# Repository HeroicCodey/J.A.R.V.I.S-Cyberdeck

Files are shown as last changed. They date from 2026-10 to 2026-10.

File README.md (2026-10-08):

# J.A.R.V.I.S-Cyberdeck
An Esp32 Based Cyberdeck using 1.8 inch TFT and four buttons (And of course 30 pin ESP-32).

The "Atlantis V2" project is a Tier 3 custom-built, portable ESP32-based cyberdeck and smart device system, featuring a firmware environment dubbed "J.A.R.V.I.S. Core V.01" or "Retro-OS". Designed by pilot/operator Sloke Bhattacharyya, the project functions as a multi-module tactical terminal integrated with cellular and network diagnostics, arcade games, and productivity tools.

**Hardware Specifications**

* **Microcontroller:** The system is powered by an ESP32 Development Board, specifically a NodeMCU-32S or ESP32-WROOM-32.
* **Display:** It utilizes a 1.8-inch SPI TFT LCD Display driven by an ST7735 controller with a 128x160 pixel resolution.
* **Input Interface:** Navigation is handled by a physical matrix of four tactile push buttons mapped to Nav, Prev, Select, and Back actions.
* **Connectivity Hardware:** Cellular capabilities are provided by an A7670C 4G LTE Module using a UART2 interface.
* **Power Architecture:** The device runs on a single 18650 Lithium-ion battery cell paired with a TP4056/BMS protection board.

**User Interface and Display Design**

* **Aesthetic Paradigm:** The interface is modeled after a simplistic, monochromatic Linux terminal.
* **Menu System:** Navigation relies on a horizontal camera-roll carousel featuring an animated viewfinder box to highlight active selections.
* **Display Orientation:** The software enforces a 180-degree display rotation (`tft.setRotation(2)`) to accommodate the physical mounting orientation of the screen.
* **Theme Engine:** The UI supports custom color palettes, including "OBSIDIAN" (black with magenta highlights), "MATRIX" (black with emerald green), and "LAPIS" (obsidian base with cyan-dominant telemetry).

**Software Modules and Applications**

* **Boot Sequence:** The system features a multi-stage fake Linux boot sequence, complete with rootfs mounting, SPI initialization, a CRT beam raster expansion effect, and an encrypted "HELLO SLOKE" operator greeting.
* **E.D.I.T.H. Tactical Diagnostics:** A dedicated network module capable of WiFi access point scanning, subnet discovery (pinging local IPs to map active hosts), and RSSI signal mapping.
* **F.R.I.D.A.Y. Web Portal:** The ESP32 hosts a local Access Point and web server that allows users to remotely configure WiFi credentials, manage a tactical "To-Do" directive list, and upload text files (TXT, JSON, CSV) directly to the device's LittleFS flash storage.
* **Productivity Tools:** The firmware includes a built-in text reader for displaying uploaded files, a virtual on-screen keyboard for standalone text entry, and a clock application featuring NTP network time synchronization, a countdown timer, and a stopwatch.
* **Arcade Games Suite:** The device includes a fully persistent, high-score tracking game engine containing six titles:
* *Space Impact:* A vertical space shooter featuring progressive difficulty, drone and interceptor enemy classes, and a dynamic spawn rate.
* *Cyber Snake:* A classic grid-based snake game.
* *Cyber Bird:* A physics-based Flappy Bird clone.
* *Firewall Breach:* A Breakout-style block-busting game.
* *Neon Overdrive:* A three-lane vertical racing/dodging game.
* *Lunar Descent:* A physics-based lunar lander simulation requiring precise thrust and angle management.

[BOM.csv](https://github.com/user-attachments/files/33223327/BOM.csv)



[Atlantis V2.pdf](https://github.com/user-attachments/files/33223259/Atlantis.V2.pdf)
Item No.,Part Name,Quantity
1,ESP32 30-pin,1
2,4-pin Tactile Button,4
3,1.8 in Touchless TFT,1

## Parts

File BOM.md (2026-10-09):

# ESP32 DEV BOARD – bill of materials

<!-- Generated by Half Life from project cmuuvkhvl0azl01sm9hbykhbl. Edits here are overwritten on the next sync. -->
<!-- Generated: 2026-10-09T17:57:20.637Z -->

> [!NOTE]
> This parts list is mirrored from [Half Life](https://halflife.hackclub.com). Editing it here will not change the platform's copy, and the next sync overwrites this file.

| Week | Tier | Parts funding |
| --- | --- | --- |
| Week 1 | Tier 2 | $65.00 |

| Part | What it's for | Qty | Unit | Total | Vendor |
| --- | --- | --- | --- | --- | --- |
| [ESP32 30-pin](https://www.digikey.com/en/products/detail/espressif-systems/ESP32-DEVKITC-32E/12091810) | Main Microcontroller | 1 | $10.00 | $10.00 | [Digikey](https://www.digikey.com/en/products/detail/espressif-systems/ESP32-DEVKITC-32E/12091810) |
| [4-pin Tactile Button](https://www.digikey.com/en/products/detail/omron-electronics-inc-emc-div/B3F-4050/36735) | Controls | 4 | $0.60 | $2.40 | [Digikey](https://www.digikey.com/en/products/detail/omron-electronics-inc-emc-div/B3F-4050/36735) |
| [1.8 in Touchless TFT](https://www.digikey.com/en/products/detail/sparkfun-electronics/15143/10064420) | Main Display | 1 | $35.00 | $35.00 | [Digikey](https://www.digikey.com/en/products/detail/sparkfun-electronics/15143/10064420) |
| [18650](https://www.digikey.com/en/products/detail/jauch-quartz/LI18650JLS-HB-3-35AH-PROTECTED/13538411) | Battery | 1 | $15.00 | $15.00 | [Digikey](https://www.digikey.com/en/products/detail/jauch-quartz/LI18650JLS-HB-3-35AH-PROTECTED/13538411) |
| **Parts subtotal** | — | — | — | **$62.40** | — |
| **Tax & shipping** | — | — | — | **$2.50** | — |
| **Total** | — | — | — | **$64.90** | — |

$0.10 left of the tier's funding.

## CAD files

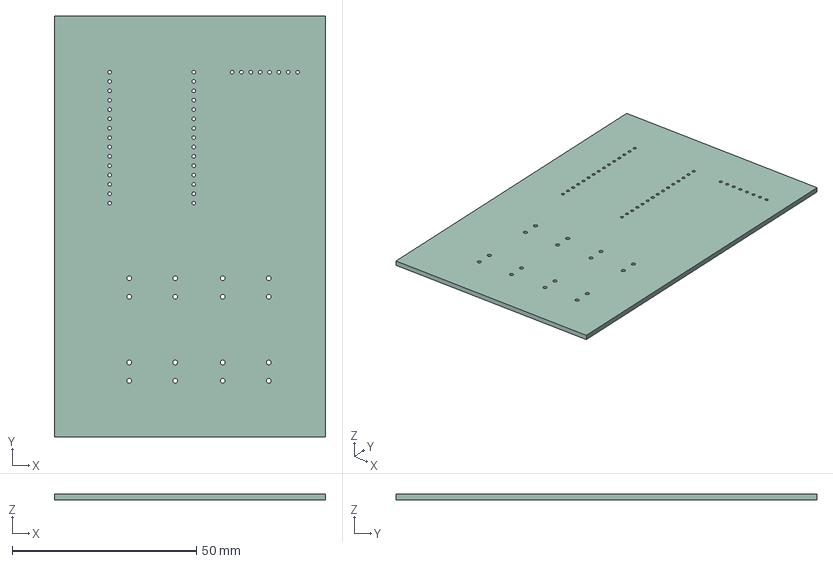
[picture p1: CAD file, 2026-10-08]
JARVIS.step
73.7 x 114.3 x 1.51 mm

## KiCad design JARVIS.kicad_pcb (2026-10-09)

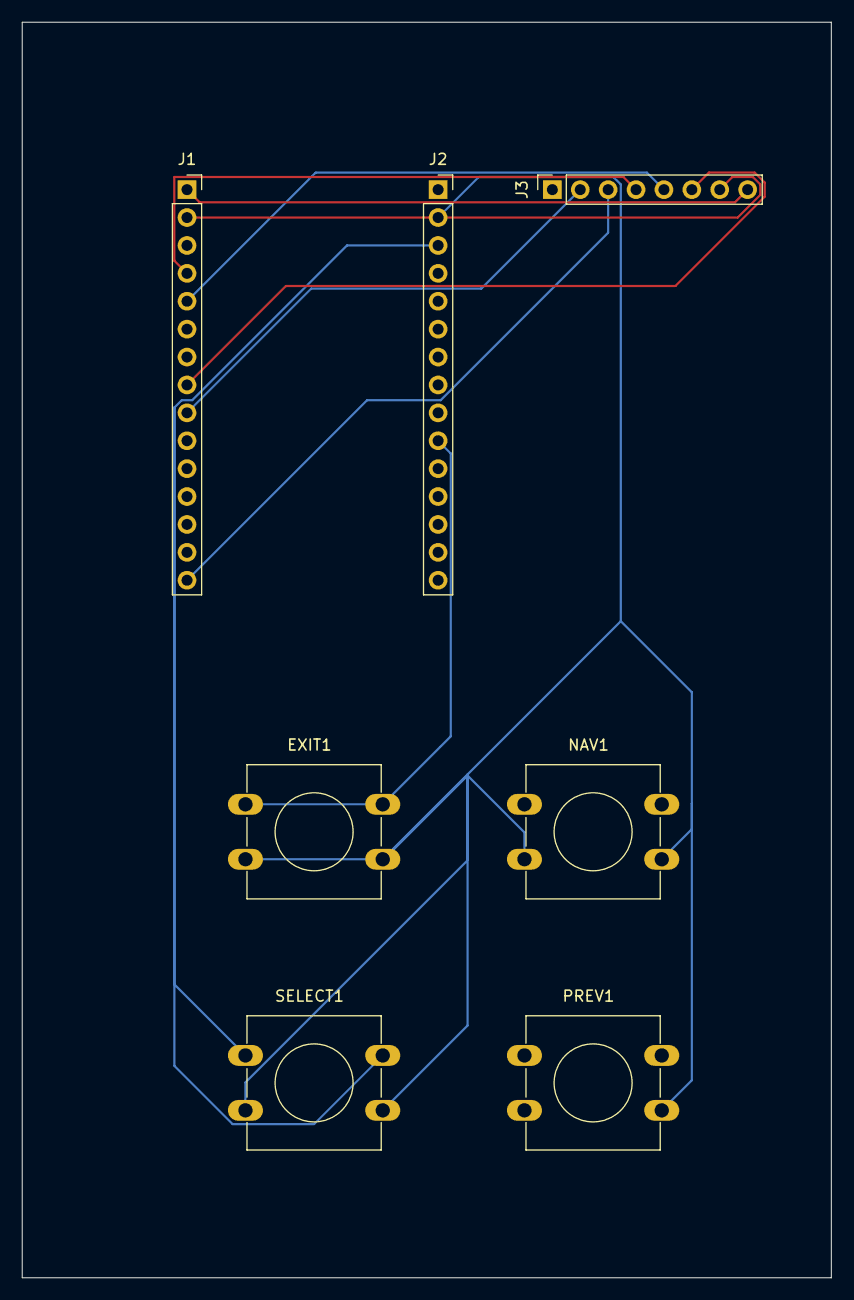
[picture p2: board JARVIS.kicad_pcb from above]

Board: 4 copper layers, 73.7 x 114.3 mm, 7 parts (0 on the bottom side), 11 nets.

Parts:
EXIT1: SW_Push; SW_PUSH-12mm
J1, J2: Conn_01x15; PinSocket_1x15_P2.54mm_Vertical
J3: Conn_01x08; PinSocket_1x08_P2.54mm_Vertical
NAV1: SW_Push; SW_PUSH-12mm
PREV1: SW_Push; SW_PUSH-12mm
SELECT1: SW_Push; SW_PUSH-12mm

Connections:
/3v3: J1.1, J3.1, J3.8
/D2: J1.4, J3.4
/D4: J1.5, J3.5
/D5: J1.8, J3.6
/D13: J2.3, SELECT1.1
/D14: J2.5, NAV1.1
/D18: J1.9, J3.2
/D23: J1.15, J3.3
/D27: J2.6, PREV1.1
/D32: EXIT1.1, J2.10
GND: EXIT1.2, J1.2, J2.2, J3.7, NAV1.2, PREV1.2, SELECT1.2

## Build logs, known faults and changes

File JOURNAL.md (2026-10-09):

# ESP32 DEV BOARD – devlog

<!-- Generated by Half Life from project cmuuvkhvl0azl01sm9hbykhbl. Edits here are overwritten on the next sync. -->
<!-- Generated: 2026-10-09T17:10:21.980Z -->

> [!NOTE]
> This devlog is mirrored from [Half Life](https://halflife.hackclub.com). Editing it here will not change the platform's copy, and the next sync overwrites this file.

> A fully functional diagnostic dev board for early prototyping. V0.01 Is the Basic version Without Sim integration.

| Week | Tier | Hours logged | Entries |
| --- | --- | --- | --- |
| Week 1 | Tier 2 | 16.03h | 3 |

## Contents

1. [2026-10-05 – Worked Out The Basics.](#2026-10-05-worked-out-the-basics)
2. [2026-10-08 – Selected Specific Parts Suitable By Going Through The Specs Sheet Of Each And Every Item. Here Are The Main Ones:](#2026-10-08-selected-specific-parts-suitable-by-going-through)
3. [2026-10-09 – Work session (3 Hours) + Creating A Writeup And Github Page (1 Hour)](#2026-10-09-work-session-3-hours-creating-a-writeup-and-githu)

## Design

### 2026-10-05 – Worked Out The Basics.

**3h**

Worked Out The Basics.
Created A List And BOM For the project. Sourced links to cheapest resources. Mapped out the UI design
to be simplistic monochromatic Linux Terminal type,
Menu: Carousel(Horizontal)
Color themes: Obsidian(Magenta), Emerald(Green),Lapis(Cyan-My fav for now)







### 2026-10-08 – Selected Specific Parts Suitable By Going Through The Specs Sheet Of Each And Every Item. Here Are The Main Ones:

**6h**

Selected Specific Parts Suitable By Going Through The Specs Sheet Of Each And Every Item. Here Are The Main Ones:



The A7670C Module supports wireless communication modes of LTE-TDD/LTE-FDD/GSM/GPRS/EDGE. It supports maximum 10Mbps downlink rate and 5Mbps uplink rate. The A7670 series supports multiple built-in network protocols, supports drivers for main operation systems (USB driver for Windows, Linux and Android etc.) and software function, AT commands are compatible with SIM7500/SIM7600 series modules.

The A7670 series adopts LGA form factor and is compatible with SIM7000/SIM7070 series, and SIM800A/SIM800F(2G modules) which enables smooth migration from 2G/NB/Cat M products to LTE Cat 1 products, and greatly facilitates more compatible product design for the customer needs.

Meanwhile the A7670 series integrates main industrial standard interfaces, with powerful expansibility, including abundant interfaces such as UART, USB, I2C, GPIO, which is suitable for main IOT applications such as telematics, surveillance devices, POS, industrial routers, remote diagnostics etc.

Features :

Small size  LTE Cat 1 module
Supports  LTE-FDD, LTE-TDD, and GSM, frequency bands
Control via AT commands
SIM Card Holder
Power LED and Network Status
Powerful TCP/IP protocol stack for internet data transfer
Supports maximum 10Mbps downlink rate and 5Mbps uplink rate
DC Jack input voltage  :  7-12V
RS232  DB9 Connector interface
SMA  connector for external antenna
1.8V UART header
Abundant software functions  : FOTA, LBS, SSL
The form factor of A7670 series are compatible with the SIM7000/SIM7070 series

Documents:

Datasheet

Package includes :

1 x A7670C 4G/2G Module

ESP32 38-Pin WiFi + Bluetooth NodeMCU Development Board
The ESP32 38-Pin WiFi + Bluetooth NodeMCU Development Board is a versatile microcontroller development board designed for IoT, home automation, robotics, embedded systems, and wireless electronics projects. Built around the ESP-WROOM-32 module, it combines a powerful dual-core processor with built-in WiFi and Bluetooth connectivity, allowing you to develop connected applications without requiring separate wireless modules.

With 38 pins and multiple GPIO, PWM, ADC, DAC, UART, SPI, and I2C interfaces, the board provides flexible connectivity for sensors, displays, motors, relays, and other electronic components. Its compatibility with the Arduino IDE makes it accessible to students and beginners while providing the processing capability required for more advanced IoT and embedded projects.

Whether you are developing a smart home system, wireless sensor network, robotics project, data logger, or connected prototype, this ESP32 development board provides a practical combination of processing power, wireless connectivity, and peripheral support.

The board is also suitable for developers looking for an affordable ESP32 NodeMCU board for IoT and embedded applications, with a large developer community and extensive software support.

Features
ESP-WROOM-32 Module
The ESP-WROOM-32 module combines processing and wireless capabilities in a compact platform, making it suitable for connected IoT and embedded applications.

Dual-Core Processor
The dual-core processor provides the processing capability needed for multitasking applications involving wireless communication, sensors, automation, and data processing.

Built-in WiFi & Bluetooth
Integrated WiFi and Bluetooth allow the board to communicate wirelessly with networks, smartphones, sensors, and other connected devices without requiring additional communication modules.

38-Pin Design
The 38-pin layout provides access to multiple GPIO and peripheral interfaces, giving developers greater flexibility when connecting sensors, displays, motors, and other components.

Arduino IDE Compatibility
Arduino IDE compatibility simplifies programming and prototyping, making the board suitable for beginners as well as experienced developers working on ESP32 projects.

Low-Power Operation
Its power-efficient design makes the ESP32 suitable for battery-powered IoT devices, wireless sensors, monitoring systems, and other embedded applications.

1.8 inch TFT LCD Module
This is the 1.8 inch TFT LCD Module. This TFT LCD display module communicates via 4-wire SPI and has its own pixel-addressable frame buffer; it can be used with any type of microcontroller, even very small ones with limited memory and few available pins.

The 1.8″ TFT LCD display features 128×160 colour pixels. This display is a true TFT, unlike low-cost “Nokia 6110” and similar LCD displays, which are CSTN type and thus have poor colour and slow refresh. The ST7735R TFT driver can display full 18-bit colour (262,144 shades!), making it ideal for vibrant graphical interfaces.

If you're comparing the 1.8 inch TFT LCD price India, this module offers a great balance between performance and affordability for DIY electronics, embedded systems, and IoT projects.

The LCD will always come with the same driver chip, so you won’t have to worry about compatibility issues across units. The TFT display is soldered to the breakout (using a delicate flex-circuit connector), along with an ultra-low-dropout 3.3V regulator and a 3/5V level shifter, allowing seamless use with both 3.3V and 5V systems.

If you want to use this 1.8 inch TFT LCD display Module with Arduino, in your project for that you will need few essential components like

breadboard
jumper wires
Features:
Display Size: 1.8 inch TFT
Resolution: 128 × 160 pixels
Driver IC: ST7735R
Interface: SPI (4-wire)
Operating Voltage: 3.3V / 5V compatible
Built-in voltage regulator and level shifter
Full RGB colour support (18-bit)
Compact and lightweight design











### 2026-10-09 – Work session (3 Hours) + Creating A Writeup And Github Page (1 Hour)

**7.03h**

Work session (3 Hours) + Creating A Writeup And Github Page (1 Hour)

[Timelapse](https://lookout.hackclub.com/api/media/f1b2b3fd-91bf-4616-979b-26d5c6f9fb0f/video.mp4)

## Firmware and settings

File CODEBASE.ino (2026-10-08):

//Code Written In Arduino Language
#include <Adafruit_GFX.h>
#include <Adafruit_ST7735.h>
#include <SPI.h>
#include <WiFi.h>
#include <esp_wifi.h>
#include <WebServer.h>
#include <LittleFS.h>
#include <time.h>
#include <Preferences.h>
#include <esp_system.h>
#include <math.h>

// =============================================================================
// HARDWARE DEFINITIONS & DISPLAY SETUP
// =============================================================================
#define TFT_CS    5
#define TFT_RST   4
#define TFT_DC    2

Adafruit_ST7735 tft = Adafruit_ST7735(TFT_CS, TFT_DC, TFT_RST);
Preferences prefs;
WebServer server(80);

#define ENABLE_PHYSICAL_BUTTONS 1

#define PIN_BTN_NAV    14  // Hardware Button 0 (Red cap)
#define PIN_BTN_PREV   27  // Hardware Button 1 (Blue cap)
#define PIN_BTN_SEL    13  // Hardware Button 2 (White cap)
#define PIN_BTN_BACK   32  // Hardware Button 3 (Amber cap)

// =============================================================================
// WI-FI & NTP CONFIGURATION
// =============================================================================
const char* WIFI_SSID     = "AirFiber+";
const char* WIFI_PASSWORD = "11223344";

const char* AP_SSID        = "FRIDAY-CORE";
const char* AP_PASS        = "cyberdeck32";

const char* NTP_SERVER_1  = "pool.ntp.org";
const char* NTP_SERVER_2  = "time.nist.gov";
const long  NTP_GMT_OFFSET_SEC      = 19800; // IST UTC+5:30
const int   NTP_DAYLIGHT_OFFSET_SEC = 0;

const unsigned long WIFI_BOOT_TIMEOUT_MS = 6000;
const unsigned long NTP_BOOT_TIMEOUT_MS  = 4000;
const size_t MIN_SAFE_HEAP_BYTES = 40960; // 40 KB Safety ceiling

// =============================================================================
// COLOR PALETTES & THEME ENGINE
// =============================================================================
struct ThemePalette {
  const char* name;
  uint16_t bg;
  uint16_t primary;
  uint16_t secondary;
  uint16_t dim;
  uint16_t steel;
  uint16_t highlight;
};

const ThemePalette THEMES[] = {
  {"OBSIDIAN",   0x0082, 0x07FF, 0xFD00, 0x03F5, 0x1A29, 0xAD7F},
  {"MATRIX",     0x0000, 0x07E0, 0x05E0, 0x0320, 0x0200, 0x87F0},
  {"SYNTHWAVE",  0x1012, 0xF81F, 0x07FF, 0x8010, 0x3018, 0xFFE0}
};
const uint8_t TOTAL_THEMES = sizeof(THEMES) / sizeof(THEMES[0]);
uint8_t currentThemeIdx = 0;

#define COLOR_BG          THEMES[currentThemeIdx].bg
#define COLOR_AMBER       THEMES[currentThemeIdx].secondary
#define COLOR_CYAN        THEMES[currentThemeIdx].primary
#define COLOR_CYAN_DIM    THEMES[currentThemeIdx].dim
#define COLOR_STEEL       THEMES[currentThemeIdx].steel
#define COLOR_ICE         THEMES[currentThemeIdx].highlight
#define COLOR_LIME        0x07E0
#define COLOR_BLACK       0x0000
#define COLOR_WHITE       0xFFFF

// Hardware Button Colors
#define HW_COLOR_RED      0xF800
#define HW_COLOR_BLUE     0x001F
#define HW_COLOR_WHITE    0xFFFF
#define HW_COLOR_AMBER    0xFBE0

const uint16_t HW_BTN_COLORS[4] = {
  HW_COLOR_RED,   
  HW_COLOR_BLUE,  
  HW_COLOR_WHITE, 
  HW_COLOR_AMBER  
};

// =============================================================================
// SYSTEM & STATE DEFINITIONS
// =============================================================================
enum BootState {
  BOOT_STATE_VERSION,
  BOOT_STATE_LINUX_LOGS,
  BOOT_STATE_CRT_BEAM,
  BOOT_STATE_RASTER_EXPAND,
  BOOT_STATE_GRID_SCAN,
  BOOT_STATE_DECRYPT_NAME,
  BOOT_STATE_SYS_LOCK,
  BOOT_STATE_IDLE
};

enum AppState {
  STATE_BOOTING, STATE_HOMESCREEN, STATE_ROLL_MENU, STATE_APP_ACTIVE,
  STATE_APP_CLOCK, STATE_APP_GAMES, STATE_APP_SETTINGS, STATE_APP_FRIDAY,
  STATE_APP_TODO, STATE_APP_READER, STATE_APP_KEYBOARD, STATE_APP_EDITH
};

enum ClockView { CLOCK_VIEW_MENU, CLOCK_VIEW_STOPWATCH, CLOCK_VIEW_TIMER, CLOCK_VIEW_SYNC };
enum GamesView { GAMES_VIEW_SELECT_GAME, GAMES_VIEW_SELECT_ACTION, GAMES_VIEW_PLAYING, GAMES_VIEW_GAMEOVER, GAMES_VIEW_HIGHSCORES };
enum SettingsView { SETTINGS_VIEW_MENU, SETTINGS_VIEW_TELEMETRY, SETTINGS_VIEW_THEME, SETTINGS_VIEW_CONTROL_MAP, SETTINGS_VIEW_STORAGE, SETTINGS_VIEW_NET_MENU, SETTINGS_VIEW_NET_STATUS, SETTINGS_VIEW_WIFI_SCAN, SETTINGS_VIEW_WIFI_CONNECTING, SETTINGS_VIEW_REBOOT };
enum ReaderView { READER_VIEW_FILE_SELECT, READER_VIEW_FILE_ACTION, READER_VIEW_READING };
enum TodoView { TODO_VIEW_LIST, TODO_VIEW_ACTION };

enum KbTargetAction {
  KB_TARGET_NONE, KB_TARGET_WIFI_PASS, KB_TARGET_TODO_ADD, KB_TARGET_FILE_RENAME
};

enum SelectedGame {
  GAME_SPACE_IMPACT = 0,
  GAME_CYBER_SNAKE  = 1,
  GAME_CYBER_BIRD   = 2,
  GAME_FIREWALL     = 3,
  GAME_OVERDRIVE    = 4,
  GAME_LUNAR        = 5
};

AppState currentAppState = STATE_BOOTING;
ClockView currentClockView = CLOCK_VIEW_MENU;
GamesView currentGamesView = GAMES_VIEW_SELECT_GAME;
SettingsView currentSettingsView = SETTINGS_VIEW_MENU;
ReaderView currentReaderView = READER_VIEW_FILE_SELECT;
TodoView currentTodoView = TODO_VIEW_LIST;
SelectedGame activeGame = GAME_SPACE_IMPACT;
KbTargetAction currentKbTarget = KB_TARGET_NONE;

int readerActionIndex = 0;
const char* readerActions[] = {"READ", "RENAME", "DELETE"};

int todoActionIndex = 0;
const char* todoActions[] = {"TOGGLE", "DELETE"};

enum InputAction { ACTION_NONE, ACTION_NAV, ACTION_PREV, ACTION_SELECT, ACTION_BACK };
enum LogicalAction { LOG_ACTION_RIGHT = 0, LOG_ACTION_LEFT = 1, LOG_ACTION_SEL = 2, LOG_ACTION_ESC = 3 };

const char* actionNames[] = {"RIGHT", "LEFT", "SELECT", "ESCAPE"};
uint8_t buttonActionMap[4] = { LOG_ACTION_RIGHT, LOG_ACTION_LEFT, LOG_ACTION_SEL, LOG_ACTION_ESC };
int controlMapCursor = 0;

uint16_t getActionColor(uint8_t targetLogicalAction) {
  for (uint8_t i = 0; i < 4; i++) {
    if (buttonActionMap[i] == targetLogicalAction) return HW_BTN_COLORS[i];
  }
  return COLOR_WHITE;
}

#define COLOR_ACT_RIGHT   getActionColor(LOG_ACTION_RIGHT)
#define COLOR_ACT_LEFT    getActionColor(LOG_ACTION_LEFT)
#define COLOR_ACT_SEL     getActionColor(LOG_ACTION_SEL)
#define COLOR_ACT_ESC     getActionColor(LOG_ACTION_ESC)

bool rtcHasBeenSynced = false;
int clockMenuIndex = 0;
const int TOTAL_CLOCK_MENU_ITEMS = 3;
const char* clockMenuItems[] = {"STOPWATCH", "TIMER", "SYNC NTP"};

int gameListIndex = 0;
const int TOTAL_GAMES = 6;
const char* gameTitles[] = {"SPACE IMPACT", "CYBER SNAKE", "CYBER BIRD", "FIREWALL BREACH", "NEON OVERDRIVE", "LUNAR DESCENT"};

int gameActionIndex = 0;
const int TOTAL_GAME_ACTIONS = 2;
const char* gameActions[] = {"PLAY", "HIGHSCORE"};

int settingsMenuIndex = 0;
const int TOTAL_SETTINGS_MENU_ITEMS = 6;
const char* settingsMenuItems[] = {"SYS TELEMETRY", "DISPLAY THEME", "CONTROL MAPPER", "STORAGE/SCORES", "NETWORK CONFIG", "REBOOT SYSTEM"};

// Added DISCONNECT WIFI option
int netMenuIndex = 0;
const int TOTAL_NET_MENU_ITEMS = 3;
const char* netMenuItems[] = {"NET TELEMETRY", "SCAN CHANNELS", "DISCONNECT WIFI"};

int lastHomeMin = -1;

// Clock Context
bool swRunning = false; unsigned long swStartTime = 0; unsigned long swElapsedTime = 0; int lastSwSec = -1;
bool tmRunning = false; unsigned long tmDuration = 60000; unsigned long tmRemaining = 60000; unsigned long tmTargetEndTime = 0; int lastTmSec = -1; int lastBarWidth = -1;
enum SyncStep { SYNC_IDLE, SYNC_CONNECT, SYNC_FETCH, SYNC_OFF };
SyncStep syncStep = SYNC_IDLE; unsigned long syncTimer = 0; int lastHeaderMinute = -1;
const char* const DAYS_OF_WEEK[] = {"SUN", "MON", "TUE", "WED", "THU", "FRI", "SAT"};

// ToDo Context
#define MAX_TODOS 12
struct ToDoItem { uint32_t id; char text[36]; char priority[10]; bool done; };
ToDoItem todoList[MAX_TODOS]; int totalTodos = 0; int todoScrollIndex = 0; int todoSelectedIdx = 0;

// Stored Networks Context
#define MAX_SAVED_NETWORKS 5
struct SavedNetwork { char ssid[33]; char pass[65]; };
SavedNetwork savedNetworks[MAX_SAVED_NETWORKS];
int totalSavedNetworks = 0;

void loadSavedNetworks() {
  prefs.begin("retro_nets", true);
  totalSavedNetworks = prefs.getInt("net_count", 0);
  if (totalSavedNetworks > MAX_SAVED_NETWORKS) totalSavedNetworks = MAX_SAVED_NETWORKS;
  for (int i = 0; i < totalSavedNetworks; i++) {
    String pfx = "n_" + String(i);
    String s = prefs.getString((pfx + "_s").c_str(), "");
    String p = prefs.getString((pfx + "_p").c_str(), "");
    strncpy(savedNetworks[i].ssid, s.c_str(), 32); savedNetworks[i].ssid[32] = '\0';
    strncpy(savedNetworks[i].pass, p.c_str(), 64); savedNetworks[i].pass[64] = '\0';
  }
  prefs.end();
  
  if (totalSavedNetworks == 0) {
    strncpy(savedNetworks[0].ssid, WIFI_SSID, 32);
    strncpy(savedNetworks[0].pass, WIFI_PASSWORD, 64);
    totalSavedNetworks = 1;
    prefs.begin("retro_nets", false);
    prefs.putInt("net_count", 1);
    prefs.putString("n_0_s", WIFI_SSID);
    prefs.putString("n_0_p", WIFI_PASSWORD);
    prefs.end();
  }
}

void saveSavedNetwork(const char* ssid, const char* pass) {
  for (int i = 0; i < totalSavedNetworks; i++) {
    if (strcmp(savedNetworks[i].ssid, ssid) == 0) {
      strncpy(savedNetworks[i].pass, pass, 64);
      prefs.begin("retro_nets", false);
      prefs.putString(("n_" + String(i) + "_p").c_str(), pass);
      prefs.end();
      return;
    }
  }
  if (totalSavedNetworks < MAX_SAVED_NETWORKS) {
    strncpy(savedNetworks[totalSavedNetworks].ssid, ssid, 32);
    strncpy(savedNetworks[totalSavedNetworks].pass, pass, 64);
    totalSavedNetworks++;
    prefs.begin("retro_nets", false);
    prefs.putInt("net_count", totalSavedNetworks);
    prefs.putString(("n_" + String(totalSavedNetworks - 1) + "_s").c_str(), ssid);
    prefs.putString(("n_" + String(totalSavedNetworks - 1) + "_p").c_str(), pass);
    prefs.end();
  }
}

// --- GAME Contexts ---
#define MAX_BULLETS 4
#define MAX_ENEMIES 4
struct Bullet { int x, y; bool active; }; struct Enemy { int x, y; int type; bool active; };
int playerX = 64; int playerLastX = 64; const int playerY = 142;
Bullet bullets[MAX_BULLETS]; Enemy enemies[MAX_ENEMIES];
long siScore = 0; long siHighScore = 0; unsigned long lastSiTick = 0; unsigned long lastEnemySpawn = 0; uint8_t enemySubstep = 0;

#define SNAKE_MAX_LEN 128
#define GRID_CELL_SIZE 4
#define GRID_OFFSET_X  8
#define GRID_OFFSET_Y  20
#define GRID_COLS      28
#define GRID_ROWS      31
enum SnakeDir { DIR_UP, DIR_RIGHT, DIR_DOWN, DIR_LEFT }; struct Point { int8_t x, y; };
Point snakeBody[SNAKE_MAX_LEN]; int snakeLen = 4; SnakeDir snakeHeading = DIR_UP; Point foodPos;
long snScore = 0; long snHighScore = 0; unsigned long lastSnakeTick = 0; unsigned long snakeSpeedMs = 130;

#define BIRD_PLAY_X1 6
#define BIRD_PLAY_X2 121
#define BIRD_PLAY_Y1 18
#define BIRD_PLAY_Y2 154
#define BIRD_X_POS   28
#define BIRD_GAP_HEIGHT 36
#define BIRD_PIPE_W  14
struct Pipe { int x; int gapY; bool passed; bool active; };
float birdY = 70.0; float birdLastY = 70.0; float birdVel = 0.0; Pipe pipes[2];
long fbScore = 0; long fbHighScore = 0; unsigned long lastFbTick = 0;

#define FW_ROWS 4
#define FW_COLS 5
struct FwBrick { int x, y, w, h; bool active; uint16_t color; };
FwBrick fwBricks[FW_ROWS * FW_COLS];
float fwBallX, fwBallY, fwBallVx, fwBallVy;
int fwPadX = 64;
long fwScore = 0; long fwHighScore = 0;
unsigned long lastFwTick = 0;

#define NO_MAX_CARS 4
struct NoCar { float y; int lane; bool active; };
NoCar noCars[NO_MAX_CARS];
int noPlayerLane = 1; // 0, 1, 2
float noBaseSpeed = 2.0; bool noOverdrive = false;
long noScore = 0; long noHighScore = 0;
unsigned long lastNoTick = 0; unsigned long lastNoSpawn = 0;

#define LD_PTS 12
struct LdPt { int x, y; };
LdPt ldTerrain[LD_PTS];
int ldPadIdx;
float ldX, ldY, ldVx, ldVy, ldAngle, ldFuel;
bool ldLastThrust = false;
long ldScore = 0; long ldHighScore = 0;
unsigned long lastLdTick = 0;

// --- Settings/Network Context ---
int scanNetworkCount = -1; int scanScrollIndex = 0; int scanSelectedIndex = 0;
char wifiTargetSSID[33] = ""; char wifiTargetPass[65] = ""; unsigned long wifiConnectTimer = 0;
bool fridayServerRunning = false; File uploadFile;

// --- Text Reader Context ---
#define MAX_READER_FILES 16
#define READER_PAGE_LINES 11
#define READER_LINE_MAX_CHARS 20
String readerFiles[MAX_READER_FILES]; int totalReaderFiles = 0; int readerFileSelected = 0; int readerFileScroll = 0;
String currentReadingPath = ""; size_t readerTotalSize = 0; size_t readerPageOffsets[64]; int readerCurrentPage = 0; int readerTotalPages = 1;

// --- Keyboard Context ---
#define KB_MAX_CHARS 32
char kbText[KB_MAX_CHARS + 1] = ""; int kbTextLen = 0; int kbActiveRow = 0; int kbCursors[4] = {0, 0, 0, 0};
bool kbNeedsRender = true; bool lastKbBlink = false;
const char kbRow0[] = "ABCDEFGHIJKLMNOPQRSTUVWXYZ"; const char kbRow1[] = "0123456789"; const char kbRow2[] = "!@#$%^&*()_+-=[]{};':\",./<>?";
const char* kbRow3[] = {"SPACE", "DEL", "ENTER", "CANCEL"}; const int kbLengths[] = {26, 10, 28, 4};

// --- E.D.I.T.H Context (Network Diagnostics) ---
enum EdithView { EDITH_VIEW_MENU, EDITH_VIEW_SUBNET_SCAN, EDITH_VIEW_SIGNAL_MAPPER, EDITH_VIEW_WIFI_LINK };
EdithView currentEdithView = EDITH_VIEW_MENU;
int edithMenuIndex = 0;
const int TOTAL_EDITH_MENU_ITEMS = 3;
const char* edithMenuItems[] = {"SUBNET DISCOVERY", "RSSI MAPPER", "LINK DEFAULT WIFI"};

unsigned long lastEdithTick = 0;
int currentPingHost = 1;
int activeHostsCount = 0;
bool subnetScanActive = false;

void setBootState(BootState newState);
void initHomeScreen(); void updateHomeScreen();
void initRollMenuScreen(); void transitionRollMenu(int direction);
void launchActiveApp();
void launchClockApp(); void initClockMenuView(); void renderClockMenu(); void updateClockApp(InputAction &input);

void launchGamesApp(); void initGamesListMenu(); void renderGamesListMenu(); void initGameActionMenu(); void renderGameActionMenu(); void updateGamesApp(InputAction &input);
void initSpaceImpact(); void updateSpaceImpact(InputAction input);
void initSnake(); void spawnSnakeFood(); void updateSnake(InputAction input);
void initCyberBird(); void updateCyberBird(InputAction input);
void initFirewall(); void updateFirewall(InputAction input);
void initOverdrive(); void updateOverdrive(InputAction input);
void initLunar(); void updateLunar(InputAction input);
void initGameOverView(); void initHighScoresView();

void launchSettingsApp(); void initSettingsMenuView(); void renderSettingsMenu(); void updateSettingsApp(InputAction &input);
void initTelemetryView(); void initThemeView(); void renderThemeView(); void initControlMapView(); void renderControlMapView();
void initStorageView(); void initNetMenuView(); void renderNetMenuView(); void initNetworkView(); void initWifiScanView(); void renderWifiScanView(); void initWifiConnectingView(); void initRebootView(); void executeRebootSequence();

void launchFridayApp(); void updateFridayApp(InputAction &input); void setupFridayServer(); void stopFridayServer();
void launchTodoApp(); void updateTodoApp(InputAction &input); void renderTodoList(); void renderTodoActionMenu(); void loadTodos(); void saveTodos();
void launchReaderApp(); void updateReaderApp(InputAction &input); void scanReaderFiles(); void renderReaderFileList(); void renderReaderActionMenu(); void openReaderDocument(const String& path); void renderReaderPage();
void launchKeyboardApp(KbTargetAction target = KB_TARGET_NONE); void updateKeyboardApp(InputAction &input);

void launchEdithApp(); void updateEdithApp(InputAction &input);
void initEdithMenu(); void renderEdithMenu();
void initEdithSubnetScan(); void initEdithSignalMapper(); void initEdithWifiLink();

// =============================================================================
// INPUT ENGINE: LOGICAL ACTION MAPPER & FILTER
// =============================================================================
const unsigned long BTN_DEBOUNCE_MS = 35;
struct ButtonChannel { uint8_t pin; bool isPressed; unsigned long pressStartTime; };
ButtonChannel buttons[] = { {PIN_BTN_NAV, false, 0}, {PIN_BTN_PREV, false, 0}, {PIN_BTN_SEL, false, 0}, {PIN_BTN_BACK, false, 0} };
const uint8_t TOTAL_BUTTONS = sizeof(buttons) / sizeof(buttons[0]);

InputAction mapLogicalToAction(uint8_t logical) {
  switch (logical) {
    case LOG_ACTION_RIGHT: return ACTION_NAV;
    case LOG_ACTION_LEFT:  return ACTION_PREV;
    case LOG_ACTION_SEL:   return ACTION_SELECT;
    case LOG_ACTION_ESC:   return ACTION_BACK;
    default:               return ACTION_NONE;
  }
}

InputAction pollInputs() {
  unsigned long now = millis();
  while (Serial.available() > 0) {
    char c = (char)Serial.read();
    if (c == '\r' || c == '\n' || c == ' ') continue;
    switch (c) {
      case 'n': case 'N': return ACTION_NAV;
      case 'p': case 'P': return ACTION_PREV;
      case 's': case 'S': return ACTION_SELECT;
      case 'b': case 'B': return ACTION_BACK;
      default: break;
    }
  }

#if ENABLE_PHYSICAL_BUTTONS
  for (uint8_t i = 0; i < TOTAL_BUTTONS; i++) {
    bool rawLow = (digitalRead(buttons[i].pin) == LOW);
    if (rawLow) {
      if (!buttons[i].isPressed) { buttons[i].isPressed = true; buttons[i].pressStartTime = now; }
    } else {
      if (buttons[i].isPressed) {
        unsigned long holdDuration = now - buttons[i].pressStartTime;
        buttons[i].isPressed = false;
        if (holdDuration >= BTN_DEBOUNCE_MS) return mapLogicalToAction(buttonActionMap[i]);
      }
    }
  }
#endif
  return ACTION_NONE;
}

// =============================================================================
// CAMERA-ROLL MENU DEFINITIONS & VECTOR ICONS
// =============================================================================
struct MenuItem { const char* title; void (*renderIcon)(int centerX, int centerY, bool isActive); };

void drawIconCall(int cx, int cy, bool isActive) {
  uint16_t primary = isActive ? COLOR_CYAN : COLOR_STEEL; uint16_t accent  = isActive ? COLOR_ICE  : COLOR_STEEL;
  tft.fillRect(cx - 7, cy - 8, 4, 3, primary); tft.fillRect(cx - 9, cy - 6, 4, 4, primary); tft.fillRect(cx - 5, cy - 5, 3, 3, primary);
  tft.fillRect(cx - 6, cy - 2, 4, 3, primary); tft.fillRect(cx - 4, cy,     4, 3, primary); tft.fillRect(cx - 2, cy + 2, 4, 3, primary); tft.fillRect(cx,     cy + 4, 4, 3, primary);
  tft.fillRect(cx + 2, cy + 5, 4, 3, primary); tft.fillRect(cx + 4, cy + 6, 4, 4, primary); tft.fillRect(cx + 7, cy + 4, 3, 4, primary);
  if (isActive) { tft.drawPixel(cx - 8, cy - 7, accent); tft.drawPixel(cx - 5, cy - 1, accent); tft.drawPixel(cx - 1, cy + 3, accent); tft.drawPixel(cx + 7, cy + 7, accent); }
}

void drawIconClock(int cx, int cy, bool isActive) {
  uint16_t primary = isActive ? COLOR_CYAN  : COLOR_STEEL; uint16_t accent  = isActive ? COLOR_AMBER : COLOR_STEEL;
  tft.fillRect(cx - 4, cy - 10, 8, 3, primary); tft.fillRect(cx - 4, cy + 8,  8, 3, primary);
  tft.drawRoundRect(cx - 9, cy - 7, 18, 15, 3, primary); tft.drawRect(cx - 7, cy - 5, 14, 11, primary);
  if (isActive) { tft.drawPixel(cx, cy, accent); tft.drawFastVLine(cx, cy - 3, 3, accent); tft.drawFastHLine(cx, cy, 4, accent); }
}

void drawIconGames(int cx, int cy, bool isActive) {
  uint16_t deckColor = isActive ? COLOR_ICE : COLOR_STEEL; uint16_t stickColor = isActive ? COLOR_CYAN : COLOR_STEEL;
  uint16_t ballColor = isActive ? HW_COLOR_RED : COLOR_STEEL; uint16_t btnAColor = isActive ? HW_COLOR_RED : COLOR_STEEL; uint16_t btnBColor = isActive ? COLOR_AMBER : COLOR_STEEL;
  tft.fillCircle(cx, cy - 6, 3, ballColor); tft.drawFastVLine(cx, cy - 3, 5, stickColor); tft.drawFastVLine(cx - 1, cy - 1, 3, stickColor); tft.drawFastVLine(cx + 1, cy - 1, 3, stickColor);
  tft.drawRoundRect(cx - 9, cy + 2, 19, 9, 2, deckColor); tft.drawFastHLine(cx - 8, cy + 8, 17, deckColor);
  tft.drawPixel(cx - 5, cy + 5, btnAColor); tft.drawPixel(cx + 4, cy + 5, btnBColor);
}

void drawIconFriday(int cx, int cy, bool isActive) {
  uint16_t ringOuter = isActive ? COLOR_CYAN : COLOR_STEEL; uint16_t ringInner = isActive ? COLOR_ICE : COLOR_STEEL; uint16_t core = isActive ? COLOR_WHITE : COLOR_STEEL;
  tft.drawCircle(cx, cy, 9, ringOuter); tft.drawCircle(cx, cy, 6, ringInner); tft.fillCircle(cx, cy, 2, core);
  if (isActive) { tft.drawFastHLine(cx - 10, cy, 3, COLOR_CYAN); tft.drawFastHLine(cx + 8, cy, 3, COLOR_CYAN); tft.drawFastVLine(cx, cy - 10, 3, COLOR_CYAN); tft.drawFastVLine(cx, cy + 8, 3, COLOR_CYAN); }
}
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
void loop() {
  InputAction input = pollInputs();

  switch (currentAppState) {
    case STATE_BOOTING: updateBootAnimation(); break;
    case STATE_HOMESCREEN: updateHomeScreen(); if (input == ACTION_SELECT) initRollMenuScreen(); break;
    case STATE_ROLL_MENU:
      if (input == ACTION_NAV) { activeRollIndex = (activeRollIndex + 1) % TOTAL_MENU_ITEMS; transitionRollMenu(1); }
      else if (input == ACTION_PREV) { activeRollIndex = (activeRollIndex - 1 + TOTAL_MENU_ITEMS) % TOTAL_MENU_ITEMS; transitionRollMenu(-1); }
      else if (input == ACTION_SELECT) { launchActiveApp(); } else if (input == ACTION_BACK) { initHomeScreen(); } break;
    case STATE_APP_ACTIVE: if (input == ACTION_BACK) initRollMenuScreen(); break;
    case STATE_APP_CLOCK: updateClockApp(input); if (input == ACTION_BACK && currentClockView == CLOCK_VIEW_MENU) initRollMenuScreen(); break;
    case STATE_APP_GAMES: updateGamesApp(input); if (input == ACTION_BACK && currentGamesView == GAMES_VIEW_SELECT_GAME) initRollMenuScreen(); break;
    case STATE_APP_SETTINGS: updateSettingsApp(input); if (input == ACTION_BACK && currentSettingsView == SETTINGS_VIEW_MENU) initRollMenuScreen(); break;
    case STATE_APP_FRIDAY: updateFridayApp(input); break;
    case STATE_APP_TODO: updateTodoApp(input); break;
    case STATE_APP_READER: updateReaderApp(input); break;
    case STATE_APP_KEYBOARD: updateKeyboardApp(input); break;
    case STATE_APP_EDITH: updateEdithApp(input); break;
  }
}

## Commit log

2026-10-08 Create PCB1
2026-10-09 Sync ESP32 DEV BOARD from Half Life
